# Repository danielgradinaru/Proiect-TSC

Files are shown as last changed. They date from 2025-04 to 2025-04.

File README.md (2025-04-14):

# eBook Reader
Diagram
Proiect hardware complet pentru un eBook Reader portabil, cu consum redus de energie, afisaj E-Paper si conectivitate moderna, proiectat in jurul microcontrollerului ESP32-C6-WROOM-1-N8.

# Arhitectura Hardware

## Microcontroller

### ESP32-C6-WROOM-1-N8
- Core RISC-V
- Conectivitate: Wi-Fi 6, Bluetooth 5
- Criptografie hardware
- [Specificații oficiale](https://www.espressif.com/en/products/modules/esp32-c6)

### Memorie Flash externă
- **W25Q512JVEIQ** – 64MB, conectată prin SPI

### Interfețe disponibile
- I2C, SPI și GPIO dedicate componentelor externe

---

## Alimentare

### USB-C (PMF0501)
- Intrare de 5V din surse standard

### Protecție ESD (USBLC6-2SC6Y)
- Protecție bidirecțională pentru liniile USB

### Încărcător Li-Po (MCP73831)
- Circuit simplu de încărcare pentru o celulă Li-Po (max. 500mA)

### Baterie
- Li-Po 3.7V

### Regulator LDO (MCP1700-3302E)
- Reglează tensiunea la 3.3V pentru alimentarea majorității componentelor

---

## Afișaj E-Ink

### Conector MP1
- Compatibil cu ecrane E-Ink de 1.54", 200x200px

### Circuit de alimentare pentru afișaj
- Componente: Q3 (tranzistor), L1 (inductor), D2 (diodă)
- Rol: generare tensiune specifică pentru EPD

### Selector tip display (SJ1)
- Jumpere pentru alegerea tipului de ecran

### Interfață
- SPI + GPIO, conectat direct la ESP32-C6

---

## Memorie Externă

- **Card SD (U4)** – pentru stocarea fișierelor eBook (conectat prin SPI)
- **64MB NOR Flash (W25Q512JVEIQ)** – memorie extinsă pentru firmware, fonturi, imagini (conectată pe SPI dedicat)

---

## Senzori și Periferice

### BME688
- Senzor pentru temperatură, umiditate, presiune și compuși volatili (VOCs)
- Comunicație: I2C

### RTC – DS3231SN
- Modul de timp real de înaltă precizie
- Comunicație: I2C

### MAX17048G-T10
- Fuel gauge pentru monitorizarea nivelului bateriei
- Comunicație: I2C

### Butoane (BD5229)
- Butoane Reset și Boot
- Conectate pe pini GPIO configurabili

### Qwiic / Stemma QT (J5)
- Conector pentru extensii rapide I2C

---

## Conexiuni ESP32-C6 (pini utilizati)

| Componenta | Interfata  | Pini ESP32-C6 | Observatii |
|---|---|---|---|
| SD Card | SPI | GPIO10, GPIO11, GPIO12, GPIO13 | Bus SPI pentru card SD |
| NOR Flash | SPI | GPIO6, GPIO7, GPIO8, GPIO9 | Bus SPI separat |
| E-Ink Display  | SPI + GPIO | GPIO18, GPIO19, GPIO20, GPIO21 | Control display si date |
| BME688 | I2C | GPIO1 (SDA), GPIO2 (SCL) | Bus comun I2C |
| DS3231 | I2C | GPIO1 (SDA), GPIO2 (SCL) | Comun cu ceilalti senzori |
| MAX17048 | I2C | GPIO1 (SDA), GPIO2 (SCL) | Comun cu ceilalti senzori |
| Butoane | GPIO | GPIO0 (RST), GPIO3 (BOOT) | Control de sistem |
| Test Pads | GPIO/UART  | GPIO17, GPIO22 | Debug |
| Stemma/Qwiic | I2C | GPIO1 (SDA), GPIO2 (SCL) | Extensii rapide |

---

## Estimare consum de energie

| Modul | Consum mediu |
|---|---|
| ESP32-C6 activ | ~80-100 mA |
| ESP32-C6 deep sleep | ~10 uA |
| E-Ink refresh | ~25 mA (temporar) |
| SD Card (idle/acces) | ~2 mA / ~50 mA |
| RTC + BME688 standby | ~3-5 uA |
| MAX17048 | ~3 uA |

**Durata estimata cu baterie 500mAh:**

- Utilizare medie: ~15-20 ore
- Standby (deep sleep): pana la cateva saptamani

---

## Informatii suplimentare

### Structura hardware
- Utilizare medie: ~15-20 ore
- Standby (deep sleep): pana la cateva saptamani

- PCB proiectat cu atentie la separarea blocurilor: alimentare, MCU, afisaj, senzori
- Plan de masa comun, trasee protejate si optimizate
- Mufe si conectori accesibili extern (USB, butoane, afisaj)

### Randari 3D si carcasa

- Randari disponibile cu componentele plasate
- Proiect finalizat atat din punct de vedere al carcasei 3D cat si al PCB
- Dimensiuni compacte si aspect ergonomic

## Aplicatii posibile

- eBook Reader offline
- Afisaj pentru date locale (calendar, vreme)

## Bill of Materials

| Name | Reference | Technical Sheet | Model Link |
|:---|:---|:---|:---|
| BOOT_BUTTON | BUTTON_CUSYOMV1 | [Datasheet](https://industry.panasonic.com/global/en/downloads?tab=catalog&small_g_cd=203&part_no=EVQPUJ02K) | [3D Model](https://industry.panasonic.com/global/en/products/control/switch/light-touch/number/evqpuj02k) |
| C1 | ESP32_WROVER_EAGLE-LTSPICE_CC0402 | [Datasheet](https://componentsearchengine.com/Datasheets/2/CC0402MRX5R5BB106.pdf) | [3D Model](https://componentsearchengine.com/part-view/CC0402MRX5R5BB106/YAGEO) |
| C1_BAT | ESP32_WROVER_EAGLE-LTSPICE_CC0402 | [Datasheet](https://componentsearchengine.com/Datasheets/2/CC0402MRX5R5BB106.pdf) | [3D Model](https://componentsearchengine.com/part-view/CC0402MRX5R5BB106/YAGEO) |
| C1_BAT1 | EAGLE-LTSPICE_CC0402 | [Datasheet](https://s3.amazonaws.com/snapeda/datasheet/CC0402DRNPO9BN5R1_Yageo.pdf) | [3D Model](https://www.snapeda.com/parts/CC0402DRNPO9BN5R1/Yageo/view-part/?ref=dk&t=LTSPICE_CC0402&con_ref=None) |
| C2_BAT1 | EAGLE-LTSPICE_CC0402 | [Datasheet](https://s3.amazonaws.com/snapeda/datasheet/CC0402DRNPO9BN5R1_Yageo.pdf) | [3D Model](https://www.snapeda.com/parts/CC0402DRNPO9BN5R1/Yageo/view-part/?ref=dk&t=LTSPICE_CC0402&con_ref=None) |
| C1_BAT2 | EAGLE-LTSPICE_CC0402 | [Datasheet](https://s3.amazonaws.com/snapeda/datasheet/CC0402DRNPO9BN5R1_Yageo.pdf) | [3D Model](https://www.snapeda.com/parts/CC0402DRNPO9BN5R1/Yageo/view-part/?ref=dk&t=LTSPICE_CC0402&con_ref=None) |
| C2 | ESP32_WROVER_EAGLE-LTSPICE_CC0402 | [Datasheet](https://componentsearchengine.com/Datasheets/2/CC0402MRX5R5BB106.pdf) | [3D Model](https://componentsearchengine.com/part-view/CC0402MRX5R5BB106/YAGEO) |
| C2_BAT | ESP32_WROVER_EAGLE-LTSPICE_CC0402 | [Datasheet](https://componentsearchengine.com/Datasheets/2/CC0402MRX5R5BB106.pdf) | [3D Model](https://componentsearchengine.com/part-view/CC0402MRX5R5BB106/YAGEO) |
| C3 | RCL_CPOL-EUCT3528 | [Datasheet](https://s3.amazonaws.com/snapeda/datasheet/TAJB475K025RNJ_AVX.pdf) | [3D Model](https://www.snapeda.com/parts/TAJB475K025RNJ/AVX/view-part/?ref=dk&t=capacitor%203528&con_ref=None) |
| C4 | ESP32_WROVER_EAGLE-LTSPICE_CC0402 | [Datasheet](https://componentsearchengine.com/Datasheets/2/CC0402MRX5R5BB106.pdf) | [3D Model](https://componentsearchengine.com/part-view/CC0402MRX5R5BB106/YAGEO) |
| C4_USB | ESP32_WROVER_EAGLE-LTSPICE_CC0402 | [Datasheet](https://componentsearchengine.com/Datasheets/2/CC0402MRX5R5BB106.pdf) | [3D Model](https://componentsearchengine.com/part-view/CC0402MRX5R5BB106/YAGEO) |
| C5 | ESP32_WROVER_EAGLE-LTSPICE_CC0402 | [Datasheet](https://componentsearchengine.com/Datasheets/2/CC0402MRX5R5BB106.pdf) | [3D Model](https://componentsearchengine.com/part-view/CC0402MRX5R5BB106/YAGEO) |
| C5_USB | ESP32_WROVER_EAGLE-LTSPICE_CC0402 | [Datasheet](https://componentsearchengine.com/Datasheets/2/CC0402MRX5R5BB106.pdf) | [3D Model](https://componentsearchengine.com/part-view/CC0402MRX5R5BB106/YAGEO) |
| C6 | ESP32_WROVER_EAGLE-LTSPICE_CC0402 | [Datasheet](https://componentsearchengine.com/Datasheets/2/CC0402MRX5R5BB106.pdf) | [3D Model](https://componentsearchengine.com/part-view/CC0402MRX5R5BB106/YAGEO) |
| C7 | ESP32_WROVER_EAGLE-LTSPICE_CC0402 | [Datasheet](https://componentsearchengine.com/Datasheets/2/CC0402MRX5R5BB106.pdf) | [3D Model](https://componentsearchengine.com/part-view/CC0402MRX5R5BB106/YAGEO) |
| C8 | ESP32_WROVER_EAGLE-LTSPICE_CC0402 | [Datasheet](https://componentsearchengine.com/Datasheets/2/CC0402MRX5R5BB106.pdf) | [3D Model](https://componentsearchengine.com/part-view/CC0402MRX5R5BB106/YAGEO) |
| C9 | EAGLE-LTSPICE_CC0402 | [Datasheet](https://s3.amazonaws.com/snapeda/datasheet/CC0402DRNPO9BN5R1_Yageo.pdf) | [3D Model](https://www.snapeda.com/parts/CC0402DRNPO9BN5R1/Yageo/view-part/?ref=dk&t=LTSPICE_CC0402&con_ref=None) |
| C10 | ESP32_WROVER_EAGLE-LTSPICE_CC0402 | [Datasheet](https://componentsearchengine.com/Datasheets/2/CC0402MRX5R5BB106.pdf) | [3D Model](https://componentsearchengine.com/part-view/CC0402MRX5R5BB106/YAGEO) |
| C10_SUPERCAP  | CPH3225A | [Datasheet](https://www.snapeda.com/parts/CPH3225A/Seiko%20Instruments/datasheet/) | [3D Model](https://www.snapeda.com/parts/CPH3225A/Seiko+Instruments/view-part/?ref=eda) |
| CHANGE_BUTTON | BUTTON_CUSYOMV1 | [Datasheet](https://industry.panasonic.com/global/en/downloads?tab=catalog&small_g_cd=203&part_no=EVQPUJ02K) | [3D Model](https://industry.panasonic.com/global/en/products/control/switch/light-touch/number/evqpuj02k) |
| CHG_LED | ADAFRUIT_LEDCHIP-LED0603 | [Datasheet](https://www.snapeda.com/parts/KP-1608SURCK/Kingbright/datasheet/) | [3D Model](https://www.snapeda.com/parts/KP-1608SURCK/Kingbright/view-part/?ref=search&t=LED%200603) |
| C_DELAY | ESP32_WROVER_EAGLE-LTSPICE_CC0402 | [Datasheet](https://componentsearchengine.com/Datasheets/2/CC0402MRX5R5BB106.pdf) | [3D Model](https://componentsearchengine.com/part-view/CC0402MRX5R5BB106/YAGEO) |
| D1 | USBLC6-2SC6Y | [Datasheet](https://www.snapeda.com/parts/USBLC6-2SC6Y/STMicroelectronics/datasheet/) | [3D Model](https://www.snapeda.com/parts/USBLC6-2SC6Y/STMicroelectronics/view-part/?ref=snap) |
| D2 | ESP32_WROVER_AVX---SD0805S020S1R0_AVX_SD0805S020S1R0_0_0AVX_SD0805S020S1R0_0_0 | [Datasheet](http://datasheets.avx.com/schottky.pdf) | [3D Model](https://ro.mouser.com/ProductDetail/KYOCERA-AVX/SD0805S020S1R0?qs=jCA%252BPfw4LHbpkAoSnwrdjw%3D%3D) |
| D3 | MBR0530 | [Datasheet](https://www.snapeda.com/parts/MBR0530/ON%20Semiconductor/datasheet/) | [3D Model](https://www.snapeda.com/parts/MBR0530/Onsemi/view-part/?ref=eda) |
| D4 | MBR0530 | [Datasheet](https://www.snapeda.com/parts/MBR0530/ON%20Semiconductor/datasheet/) | [3D Model](https://www.snapeda.com/parts/MBR0530/Onsemi/view-part/?ref=eda) |
| D5 | MBR0530 | [Datasheet](https://www.snapeda.com/parts/MBR0530/ON%20Semiconductor/datasheet/) | [3D Model](https://www.snapeda.com/parts/MBR0530/Onsemi/view-part/?ref=eda) |
| D6 | PGB1010603MR | [Datasheet](https://www.snapeda.com/parts/PGB1010603MR/Littelfuse%20Inc./datasheet/) | [3D Model](https://www.snapeda.com/parts/PGB1010603MR/Littelfuse/view-part/?ref=eda) |
| D7 | ESP32_WROVER_AVX---SD0805S020S1R0_AVX_SD0805S020S1R0_0_0AVX_SD0805S020S1R0_0_0 | [Datasheet](http://datasheets.avx.com/schottky.pdf) | [3D Model](https://eu.mouser.com/ProductDetail/KYOCERA-AVX/SD0805S020S1R0?qs=jCA%252BPfw4LHbpkAoSnwrdjw%3D%3D) |
| D8 | PGB1010603MR | [Datasheet](https://www.snapeda.com/parts/PGB1010603MR/Littelfuse%20Inc./datasheet/) | [3D Model](https://www.snapeda.com/parts/PGB1010603MR/Littelfuse/view-part/?ref=eda) |
| D9 | PGB1010603MR | [Datasheet](https://www.snapeda.com/parts/PGB1010603MR/Littelfuse%20Inc./datasheet/) | [3D Model](https://www.snapeda.com/parts/PGB1010603MR/Littelfuse/view-part/?ref=eda) |
| D10 | PGB1010603MR | [Datasheet](https://www.snapeda.com/parts/PGB1010603MR/Littelfuse%20Inc./datasheet/) | [3D Model](https://www.snapeda.com/parts/PGB1010603MR/Littelfuse/view-part/?ref=eda) |
| D11 | PGB1010603MR | [Datasheet](https://www.snapeda.com/parts/PGB1010603MR/Littelfuse%20Inc./datasheet/) | [3D Model](https://www.snapeda.com/parts/PGB1010603MR/Littelfuse/view-part/?ref=eda) |
| D12 | PGB1010603MR | [Datasheet](https://www.snapeda.com/parts/PGB1010603MR/Littelfuse%20Inc./datasheet/) | [3D Model](https://www.snapeda.com/parts/PGB1010603MR/Littelfuse/view-part/?ref=eda) |
| EPD_C1 | ESP32_WROVER_EAGLE-LTSPICE_CC0402 | [Datasheet](https://componentsearchengine.com/Datasheets/2/CC0402MRX5R5BB106.pdf) | [3D Model](https://componentsearchengine.com/part-view/CC0402MRX5R5BB106/YAGEO) |
| EPD_C2 | ESP32_WROVER_EAGLE-LTSPICE_CC0402 | [Datasheet](https://componentsearchengine.com/Datasheets/2/CC0402MRX5R5BB106.pdf) | [3D Model](https://componentsearchengine.com/part-view/CC0402MRX5R5BB106/YAGEO) |
| EPD_C5 | ESP32_WROVER_EAGLE-LTSPICE_CC0402 | [Datasheet](https://componentsearchengine.com/Datasheets/2/CC0402MRX5R5BB106.pdf) | [3D Model](https://componentsearchengine.com/part-view/CC0402MRX5R5BB106/YAGEO) |
| EPD_C6 | ESP32_WROVER_EAGLE-LTSPICE_CC0402 | [Datasheet](https://componentsearchengine.com/Datasheets/2/CC0402MRX5R5BB106.pdf) | [3D Model](https://componentsearchengine.com/part-view/CC0402MRX5R5BB106/YAGEO) |
| EPD_C7 | ESP32_WROVER_EAGLE-LTSPICE_CC0402 | [Datasheet](https://componentsearchengine.com/Datasheets/2/CC0402MRX5R5BB106.pdf) | [3D Model](https://componentsearchengine.com/part-view/CC0402MRX5R5BB106/YAGEO) |
| EPD_C8 | ESP32_WROVER_EAGLE-LTSPICE_CC0402 | [Datasheet](https://componentsearchengine.com/Datasheets/2/CC0402MRX5R5BB106.pdf) | [3D Model](https://componentsearchengine.com/part-view/CC0402MRX5R5BB106/YAGEO) |
| EPD_C9 | ESP32_WROVER_EAGLE-LTSPICE_CC0402 | [Datasheet](https://componentsearchengine.com/Datasheets/2/CC0402MRX5R5BB106.pdf) | [3D Model](https://componentsearchengine.com/part-view/CC0402MRX5R5BB106/YAGEO) |
| EPD_C10 | ESP32_WROVER_EAGLE-LTSPICE_CC0402 | [Datasheet](https://componentsearchengine.com/Datasheets/2/CC0402MRX5R5BB106.pdf) | [3D Model](https://componentsearchengine.com/part-view/CC0402MRX5R5BB106/YAGEO) |
| EPD_C11 | ESP32_WROVER_EAGLE-LTSPICE_CC0402 | [Datasheet](https://componentsearchengine.com/Datasheets/2/CC0402MRX5R5BB106.pdf) | [3D Model](https://componentsearchengine.com/part-view/CC0402MRX5R5BB106/YAGEO) |
| EPD_C12 | ESP32_WROVER_EAGLE-LTSPICE_CC0402 | [Datasheet](https://componentsearchengine.com/Datasheets/2/CC0402MRX5R5BB106.pdf) | [3D Model](https://componentsearchengine.com/part-view/CC0402MRX5R5BB106/YAGEO) |
| IC1 | BD5229G-TR | [Datasheet](https://datasheet.datasheetarchive.com/originals/distributors/Datasheets_SAMA/f2b9741ef86007909f138d561a359946.pdf) | [3D Model](https://componentsearchengine.com/part-view/BD5229G-TR/ROHM%20Semiconductor) |
| IC4 | XC6220A331MR-G | [Datasheet](https://product.torexsemi.com/system/files/series/xc6220.pdf) | [3D Model](https://componentsearchengine.com/part-view/XC6220A331MR-G/Torex) |
| J1 | FH34SRJ-24S-0.5SH_99_ | [Datasheet](https://www.hirose.com/en/product/document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) | [3D Model](https://componentsearchengine.com/part-view/FH34SRJ-24S-0.5SH(99)/Hirose) |
| J2 | SAMACSYS_PARTS_USB4110-GF-A | [Datasheet](https://gct.co/files/drawings/usb4110.pdf) | [3D Model](https://componentsearchengine.com/part-view/USB4110-GF-A/GCT%20(GLOBAL%20CONNECTOR%20TECHNOLOGY)) |
| J3 | QWIIC_CONNECTORJS-1MM | [Datasheet](https://eu.mouser.com/ProductDetail/Adafruit/4208?qs=PzGy0jfpSMtbScLbr0L5dw%3D%3D) | [3D Model](https://grabcad.com/library/sparkfun-qwiic-right-angle-1) |
| J4 | 112A-TAAR-R03_ATTEND | [Datasheet](https://store.comet.srl.ro/Catalogue/Product/43497/) | [3D Model](https://store.comet.srl.ro/Catalogue/Product/43497/) |
| L1 | 744043680IND_4828-WE-TPC_WRE | [Datasheet](https://www.we-online.com/components/products/datasheet/744043680.pdf) | [3D Model](https://ro.mouser.com/ProductDetail/Wurth-Elektronik/744043680?qs=PGXP4M47uW6VkZq%252BkzjrHA%3D%3D) |
| PFMF.050.1 | ESP32C6_VARISTORCN1812 | [Datasheet](https://www.mouser.co.uk/ProductDetail/EPCOS-TDK/B72520T0350K062?qs=dEfas%2FXlABIszF52uu7vrg%3D%3D) | [3D Model](https://www.mouser.co.uk/ProductDetail/EPCOS-TDK/B72520T0350K062?qs=dEfas%2FXlABIszF52uu7vrg%3D%3D) |
| Q1 | ESP32_WROVER_SPARKFUN-DISCRETESEMI_MOSFET_PCH-DMG2305UX-7 | [Datasheet](https://www.diodes.com//assets/Datasheets/DMG2305UX.pdf) | [3D Model](https://componentsearchengine.com/part-view/DMG2305UX-7/Diodes%20Incorporated) |
| Q2 | ESP32_WROVER_SPARKFUN-DISCRETESEMI_MOSFET_PCH-DMG2305UX-7 | [Datasheet](https://www.diodes.com//assets/Datasheets/DMG2305UX.pdf) | [3D Model](https://componentsearchengine.com/part-view/DMG2305UX-7/Diodes%20Incorporated) |
| Q3 | D8 | [Datasheet](https://componentsearchengine.com/Datasheets/1/SI1308EDL-T1-GE3.pdf) | [3D Model](https://componentsearchengine.com/part-view/SI1308EDL-T1-GE3/Vishay) |
| R1 | ESP32_WROVER_EAGLE-LTSPICE_RR0402 | [Datasheet](https://www.yageo.com/upload/media/product/products/datasheet/rchip/PYu-RC_Group_51_RoHS_L_12.pdf) | [3D Model](https://componentsearchengine.com/part-view/R0402%201%25%20100%20K%20(RC0402FR-07100KL)/YAGEO) |
| R1-PINH | ESP32_WROVER_EAGLE-LTSPICE_RR0402 | [Datasheet](https://www.yageo.com/upload/media/product/products/datasheet/rchip/PYu-RC_Group_51_RoHS_L_12.pdf) | [3D Model](https://componentsearchengine.com/part-view/R0402%201%25%20100%20K%20(RC0402FR-07100KL)/YAGEO) |
| R1-PINH1 | ESP32_WROVER_EAGLE-LTSPICE_RR0402 | [Datasheet](https://www.yageo.com/upload/media/product/products/datasheet/rchip/PYu-RC_Group_51_RoHS_L_12.pdf) | [3D Model](https://componentsearchengine.com/part-view/R0402%201%25%20100%20K%20(RC0402FR-07100KL)/YAGEO) |
| R1_BAT | ESP32_WROVER_EAGLE-LTSPICE_RR0402 | [Datasheet](https://www.yageo.com/upload/media/product/products/datasheet/rchip/PYu-RC_Group_51_RoHS_L_12.pdf) | [3D Model](https://componentsearchengine.com/part-view/R0402%201%25%20100%20K%20(RC0402FR-07100KL)/YAGEO) |
| R1_PWRUSB | ESP32_WROVER_EAGLE-LTSPICE_RR0402 | [Datasheet](https://www.yageo.com/upload/media/product/products/datasheet/rchip/PYu-RC_Group_51_RoHS_L_12.pdf) | [3D Model](https://componentsearchengine.com/part-view/R0402%201%25%20100%20K%20(RC0402FR-07100KL)/YAGEO) |
| R2 | ESP32_WROVER_EAGLE-LTSPICE_RR0402 | [Datasheet](https://www.yageo.com/upload/media/product/products/datasheet/rchip/PYu-RC_Group_51_RoHS_L_12.pdf) | [3D Model](https://componentsearchengine.com/part-view/R0402%201%25%20100%20K%20(RC0402FR-07100KL)/YAGEO) |
| R2-PINH | ESP32_WROVER_EAGLE-LTSPICE_RR0402 | [Datasheet](https://www.yageo.com/upload/media/product/products/datasheet/rchip/PYu-RC_Group_51_RoHS_L_12.pdf) | [3D Model](https://componentsearchengine.com/part-view/R0402%201%25%20100%20K%20(RC0402FR-07100KL)/YAGEO) |
| R2-PINH1 | ESP32_WROVER_EAGLE-LTSPICE_RR0402 | [Datasheet](https://www.yageo.com/upload/media/product/products/datasheet/rchip/PYu-RC_Group_51_RoHS_L_12.pdf) | [3D Model](https://componentsearchengine.com/part-view/R0402%201%25%20100%20K%20(RC0402FR-07100KL)/YAGEO) |
| R2-USB | ESP32_WROVER_EAGLE-LTSPICE_RR0402 | [Datasheet](https://www.yageo.com/upload/media/product/products/datasheet/rchip/PYu-RC_Group_51_RoHS_L_12.pdf) | [3D Model](https://componentsearchengine.com/part-view/R0402%201%25%20100%20K%20(RC0402FR-07100KL)/YAGEO) |
| R2-USB1 | ESP32_WROVER_EAGLE-LTSPICE_RR0402 | [Datasheet](https://www.yageo.com/upload/media/product/products/datasheet/rchip/PYu-RC_Group_51_RoHS_L_12.pdf) | [3D Model](https://componentsearchengine.com/part-view/R0402%201%25%20100%20K%20(RC0402FR-07100KL)/YAGEO) |
| R2_BAT | ESP32_WROVER_EAGLE-LTSPICE_RR0402 | [Datasheet](https://www.yageo.com/upload/media/product/products/datasheet/rchip/PYu-RC_Group_51_RoHS_L_12.pdf) | [3D Model](https://componentsearchengine.com/part-view/R0402%201%25%20100%20K%20(RC0402FR-07100KL)/YAGEO) |
| R3 | ESP32_WROVER_EAGLE-LTSPICE_RR0402 | [Datasheet](https://www.yageo.com/upload/media/product/products/datasheet/rchip/PYu-RC_Group_51_RoHS_L_12.pdf) | [3D Model](https://componentsearchengine.com/part-view/R0402%201%25%20100%20K%20(RC0402FR-07100KL)/YAGEO) |
| R4 | ESP32_WROVER_EAGLE-LTSPICE_RR0402 | [Datasheet](https://www.yageo.com/upload/media/product/products/datasheet/rchip/PYu-RC_Group_51_RoHS_L_12.pdf) | [3D Model](https://componentsearchengine.com/part-view/R0402%201%25%20100%20K%20(RC0402FR-07100KL)/YAGEO) |
| R5 | ESP32_WROVER_EAGLE-LTSPICE_RR0402 | [Datasheet](https://www.yageo.com/upload/media/product/products/datasheet/rchip/PYu-RC_Group_51_RoHS_L_12.pdf) | [3D Model](https://componentsearchengine.com/part-view/R0402%201%25%20100%20K%20(RC0402FR-07100KL)/YAGEO) |
| R6 | ESP32_WROVER_EAGLE-LTSPICE_RR0402 | [Datasheet](https://www.yageo.com/upload/media/product/products/datasheet/rchip/PYu-RC_Group_51_RoHS_L_12.pdf) | [3D Model](https://componentsearchengine.com/part-view/R0402%201%25%20100%20K%20(RC0402FR-07100KL)/YAGEO) |
| R7 | ESP32_WROVER_EAGLE-LTSPICE_RR0402 | [Datasheet](https://www.yageo.com/upload/media/product/products/datasheet/rchip/PYu-RC_Group_51_RoHS_L_12.pdf) | [3D Model](https://componentsearchengine.com/part-view/R0402%201%25%20100%20K%20(RC0402FR-07100KL)/YAGEO) |
| R8 | ESP32_WROVER_EAGLE-LTSPICE_RR0402 | [Datasheet](https://www.yageo.com/upload/media/product/products/datasheet/rchip/PYu-RC_Group_51_RoHS_L_12.pdf) | [3D Model](https://componentsearchengine.com/part-view/R0402%201%25%20100%20K%20(RC0402FR-07100KL)/YAGEO) |
| R9 | ESP32_WROVER_EAGLE-LTSPICE_RR0402 | [Datasheet](https://www.yageo.com/upload/media/product/products/datasheet/rchip/PYu-RC_Group_51_RoHS_L_12.pdf) | [3D Model](https://componentsearchengine.com/part-view/R0402%201%25%20100%20K%20(RC0402FR-07100KL)/YAGEO) |
| R10 | ESP32_WROVER_EAGLE-LTSPICE_RR0402 | [Datasheet](https://www.yageo.com/upload/media/product/products/datasheet/rchip/PYu-RC_Group_51_RoHS_L_12.pdf) | [3D Model](https://componentsearchengine.com/part-view/R0402%201%25%20100%20K%20(RC0402FR-07100KL)/YAGEO) |
| RESET_BUTTON  | BUTTON_CUSYOMV1 | [Datasheet](https://industry.panasonic.com/global/en/downloads?tab=catalog&small_g_cd=203&part_no=EVQPUJ02K) | [3D Model](https://industry.panasonic.com/global/en/products/control/switch/light-touch/number/evqpuj02k) |
| R_BOOT | ESP32_WROVER_EAGLE-LTSPICE_RR0402 | [Datasheet](https://www.yageo.com/upload/media/product/products/datasheet/rchip/PYu-RC_Group_51_RoHS_L_12.pdf) | [3D Model](https://componentsearchengine.com/part-view/R0402%201%25%20100%20K%20(RC0402FR-07100KL)/YAGEO) |
| R_CAPACITOR | ESP32_WROVER_EAGLE-LTSPICE_RR0402 | [Datasheet](https://www.yageo.com/upload/media/product/products/datasheet/rchip/PYu-RC_Group_51_RoHS_L_12.pdf) | [3D Model](https://componentsearchengine.com/part-view/R0402%201%25%20100%20K%20(RC0402FR-07100KL)/YAGEO) |
| R_CHANGE | ESP32_WROVER_EAGLE-LTSPICE_RR0402 | [Datasheet](https://www.yageo.com/upload/media/product/products/datasheet/rchip/PYu-RC_Group_51_RoHS_L_12.pdf) | [3D Model](https://componentsearchengine.com/part-view/R0402%201%25%20100%20K%20(RC0402FR-07100KL)/YAGEO) |
| R_CL1 | ESP32_WROVER_EAGLE-LTSPICE_RR0402 | [Datasheet](https://www.yageo.com/upload/media/product/products/datasheet/rchip/PYu-RC_Group_51_RoHS_L_12.pdf) | [3D Model](https://componentsearchengine.com/part-view/R0402%201%25%20100%20K%20(RC0402FR-07100KL)/YAGEO) |
| R_RESET | ESP32_WROVER_EAGLE-LTSPICE_RR0402 | [Datasheet](https://www.yageo.com/upload/media/product/products/datasheet/rchip/PYu-RC_Group_51_RoHS_L_12.pdf) | [3D Model](https://componentsearchengine.com/part-view/R0402%201%25%20100%20K%20(RC0402FR-07100KL)/YAGEO) |
| SENSOR2 | ESP32_WROVER_BME680_BME680 | [Datasheet](https://www.snapeda.com/parts/BME680/Bosch%20Sensortec/datasheet/) | [3D Model](https://www.snapeda.com/parts/BME680/Bosch/view-part/?welcome=home) |
| SJ1 | SJ | [Datasheet](https://www.digikey.com/en/htmldatasheets/production/1809569/0/0/1/jumpers) | [3D Model](https://grabcad.com/library/solder-jumpers-1) |
| U1 | W25Q512JVEIQ | [Datasheet](https://www.snapeda.com/parts/W25Q512JVEIQ/Winbond%20Electronics/datasheet/) | [3D Model](https://www.snapeda.com/parts/W25Q512JVEIQ/Winbond+Electronics/view-part/?ref=eda) |
| U2 | ESP32-C6-WROOM-1-N8 | [Datasheet](https://www.snapeda.com/parts/ESP32-C6-WROOM-1-N8/Espressif%20Systems/datasheet/) | [3D Model](https://www.snapeda.com/parts/ESP32-C6-WROOM-1-N8/Espressif+Systems/view-part/?ref=eda) |
| U3 | DS3231SN# | [Datasheet](https://www.snapeda.com/parts/DS3231SN%23/Analog%20Devices/datasheet/) | [3D Model](https://www.snapeda.com/parts/DS3231SN%23/Analog+Devices/view-part/?ref=eda) |
| U4 | MAX17048G+T10 | [Datasheet](https://www.snapeda.com/parts/MAX17048G+T10/Analog%20Devices/datasheet/) | [3D Model](https://www.snapeda.com/parts/MAX17048G+T10/Analog+Devices/view-part/?ref=eda) |
| U5 | ESP32_WROVER_SPARKFUN-IC-POWER_MCP73831 | [Datasheet](https://ro.mouser.com/datasheet/2/268/MCP73831_Family_Data_Sheet_DS20001984H-3441711.pdf) | [3D Model](https://ro.mouser.com/ProductDetail/Microchip-Technology/MCP73831T-2ACI-OT?qs=yUQqVecv4qvbBQBGbHx0Mw%3D%3D) |
| TP1 | TPTP20R | | |
| TP2 | TPTP20R | | |
| TP3 | TPTP20R | | |
| TP4 | TPTP20R | | |
| TP5 | TPTP20R | | |
| TP6 | TPTP20R | | |
| TP7 | TPTP20R | | |
| TP8 | TPTP20R | | |
| TP9 | TPTP20R | | |
| TP10 | TPTP20R | | |
| TP11 | TPTP20R | | |
| TP12 | TPTP20R | | |
| TP13 | TPTP20R | | |
| TP14 | TPTP20R | | |
| TP15 | TPTP20R | | |
| TP16 | TPTP20R | | |

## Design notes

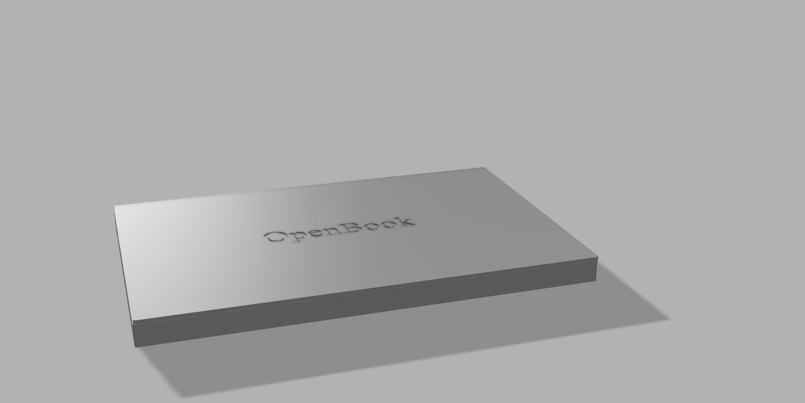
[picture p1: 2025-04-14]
Images/Back.png

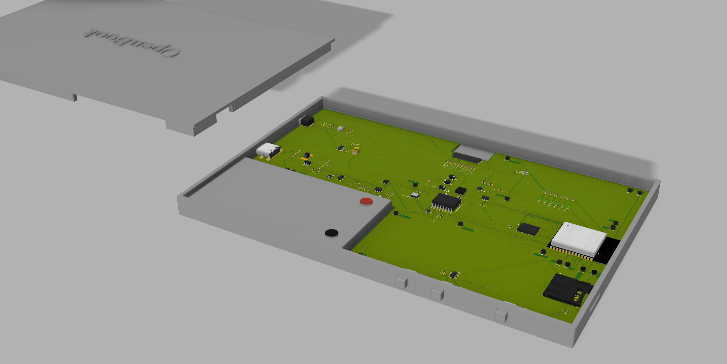
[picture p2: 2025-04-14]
Images/PCB2.png

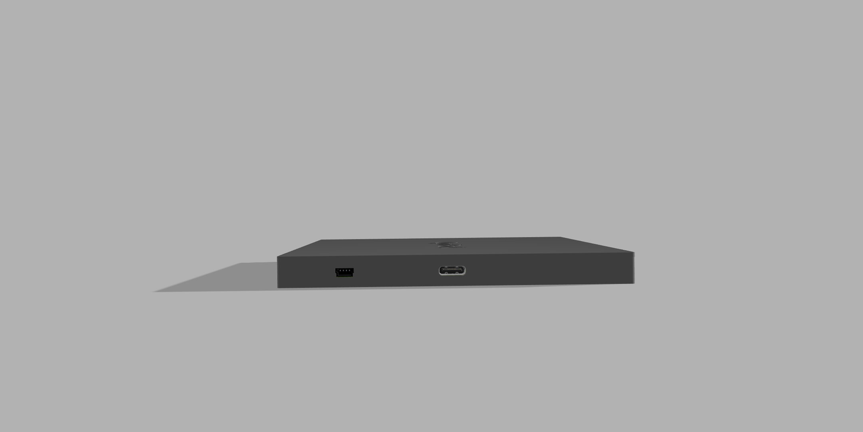
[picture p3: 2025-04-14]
Images/Side.png

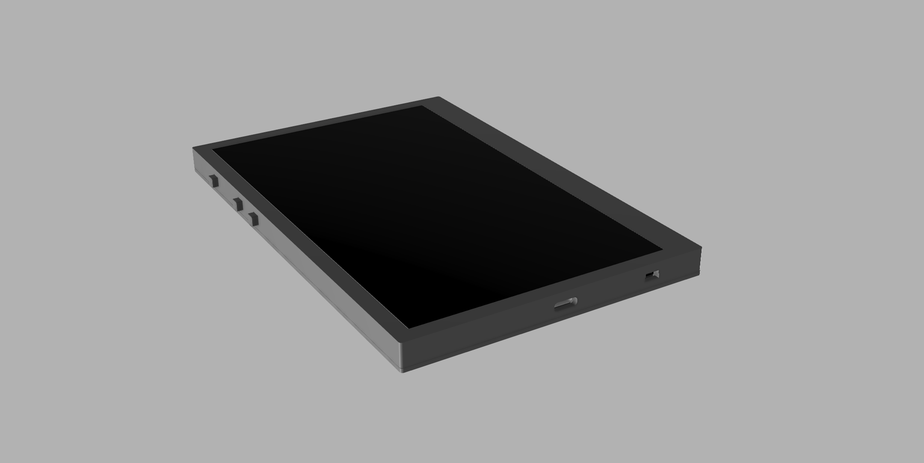
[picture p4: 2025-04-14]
Images/Front.png

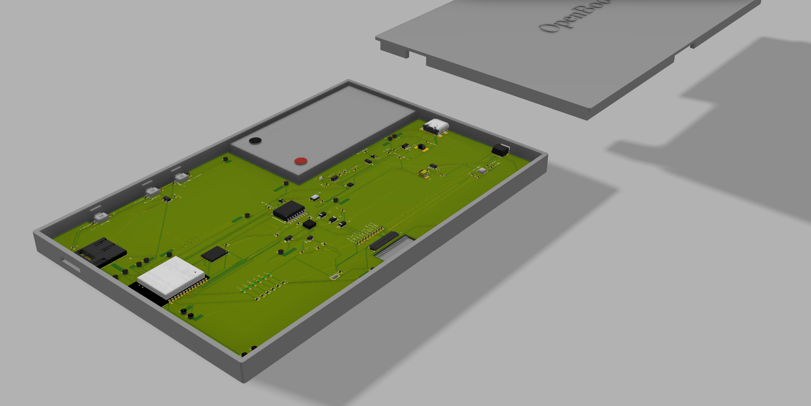
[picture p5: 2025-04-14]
Images/PCB.png

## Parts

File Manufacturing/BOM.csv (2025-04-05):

Qty | Value | Device | Package | Parts | Description | ARROW_PART_NUMBER | ARROW_PRICE-STOCK | AVAILABILITY | CENTROID_NOT_SPECIFIED | CHECK_PRICES | COPYRIGHT | DATASHEET | DESCRIPTION | DIGIKEY_DESCRIPTION | DIGIKEY_PART_NUMBER | HEIGHT | LEAD_FREE | MANUFACTURER_NAME | MANUFACTURER_PART_NUMBER | MF | MFR_NAME | MOUSER_PART_NUMBER | MOUSER_PRICE-STOCK | MOUSER_TESTING_PART_NUMBER | MOUSER_TESTING_PRICE-STOCK | MP | MPN | PACKAGE | POPULARITY | PREFIX | PRICE | PROD_ID | PURCHASE-URL | ROHS | SNAPEDA_LINK | SPICEMODEL | SPICEPREFIX | TEMPERATURE_RANGE_HIGH | TEMPERATURE_RANGE_LOW | TP_SIGNAL_NAME | VALUE
1 |  | ADAFRUIT_LEDCHIP-LED0603 | ADAFRUIT_CHIP-LED0603 | CHG_LED | LED
1 |  | SJ | SJ | SJ1 | SMD solder JUMPER |  |  |  |  |  |  |  |  |  |  |  |  |  |  |  |  |  |  |  |  |  |  |  | 3
1 | 0.47 | ESP32_WROVER_EAGLE-LTSPICE_RR0402 | ESP32_WROVER_EAGLE-LTSPICE_R0402 | R3 | RESISTOR, European symbol |  |  |  |  |  |  |  |  |  |  |  |  |  |  |  |  |  |  |  |  |  |  |  |  |  |  |  |  |  |  | NONE | R
1 | 100K | ESP32_WROVER_EAGLE-LTSPICE_RR0402 | ESP32_WROVER_EAGLE-LTSPICE_R0402 | R1_PWRUSB | RESISTOR, European symbol |  |  |  |  |  |  |  |  |  |  |  |  |  |  |  |  |  |  |  |  |  |  |  |  |  |  |  |  |  |  | NONE | R
8 | 100nF | EAGLE-LTSPICE_CC0402 | EAGLE-LTSPICE_C0402 | C1, C2, C4_USB, C6, C8, C9, C10, C_DELAY | CAPACITOR, European symbol |  |  |  |  |  |  |  |  |  |  |  |  |  |  |  |  |  |  |  |  |  |  |  |  |  |  |  |  |  |  | NONE | C
1 | 100uF | RCL_CPOL-EUCT3528 | RCL_CT3528 | C3 | POLARIZED CAPACITOR, European symbol |  |  |  |  |  |  |  |  |  |  |  |  |  |  |  |  |  |  |  |  |  |  |  | 0 |  |  |  |  |  |  |  | C
16 | 10K | ESP32_WROVER_EAGLE-LTSPICE_RR0402 | ESP32_WROVER_EAGLE-LTSPICE_R0402 | R1, R1-PINH, R1_PINH1, R2-PINH, R2_PINH1, R4, R5, R6, R7, R8, R9, R10, R_BOOT, R_CHANGE, R_CL1, R_RESET | RESISTOR, European symbol |  |  |  |  |  |  |  |  |  |  |  |  |  |  |  |  |  |  |  |  |  |  |  |  |  |  |  |  |  |  | NONE | R
1 | 10uF | EAGLE-LTSPICE_CC0402 | EAGLE-LTSPICE_C0402 | C7 | CAPACITOR, European symbol |  |  |  |  |  |  |  |  |  |  |  |  |  |  |  |  |  |  |  |  |  |  |  |  |  |  |  |  |  |  | NONE | C
1 | 112A-TAAR-R03_ATTEND | 112A-TAAR-R03_ATTEND | 112ATAARR03ATTEND | J4 | Micro SD Card Socket, Push-Push Type, Top Mount, SMT, H=1.83mm, 10u |  |  |  |  |  |  |  | Micro SD Card Socket | Push-Push Type | Top Mount | SMT | H=1.83mm | 10u |  |  | 1.9mm |  | ATTEND | 112A-TAAR-R03 ATTEND
1 | 15 | ESP32_WROVER_EAGLE-LTSPICE_RR0402 | ESP32_WROVER_EAGLE-LTSPICE_R0402 | R_CAPACITOR | RESISTOR, European symbol |  |  |  |  |  |  |  |  |  |  |  |  |  |  |  |  |  |  |  |  |  |  |  |  |  |  |  |  |  |  | NONE | R
1 | 1uF | EAGLE-LTSPICE_CC0402 | EAGLE-LTSPICE_C0402 | C5 | CAPACITOR, European symbol |  |  |  |  |  |  |  |  |  |  |  |  |  |  |  |  |  |  |  |  |  |  |  |  |  |  |  |  |  |  | NONE | C
10 | 1uF/50V | EAGLE-LTSPICE_CC0402 | EAGLE-LTSPICE_C0402 | EPD_C1, EPD_C2, EPD_C5, EPD_C6, EPD_C7, EPD_C8, EPD_C9, EPD_C10, EPD_C11, EPD_C12 | CAPACITOR, European symbol |  |  |  |  |  |  |  |  |  |  |  |  |  |  |  |  |  |  |  |  |  |  |  |  |  |  |  |  |  |  | NONE | C
1 | 2.2 | ESP32_WROVER_EAGLE-LTSPICE_RR0402 | ESP32_WROVER_EAGLE-LTSPICE_R0402 | R2 | RESISTOR, European symbol |  |  |  |  |  |  |  |  |  |  |  |  |  |  |  |  |  |  |  |  |  |  |  |  |  |  |  |  |  |  | NONE | R
1 | 200 | ESP32_WROVER_EAGLE-LTSPICE_RR0402 | ESP32_WROVER_EAGLE-LTSPICE_R0402 | R1_BAT | RESISTOR, European symbol |  |  |  |  |  |  |  |  |  |  |  |  |  |  |  |  |  |  |  |  |  |  |  |  |  |  |  |  |  |  | NONE | R
2 | 20V/4.2A/52m?/1.4W | ESP32_WROVER_SPARKFUN-DISCRETESEMI_MOSFET_PCH-DMG2305UX-7 | ESP32_WROVER_SPARKFUN-DISCRETESEMI_SOT23-3 | Q1, Q2 | P-channel MOSFETs |  |  |  |  |  |  |  |  |  |  |  |  |  |  |  |  |  |  |  |  |  |  |  |  |  |  | TRAN-14388 |  |  |  |  |  |  |  |  | 20V/4.2A/52m?/1.4W
1 | 2K | ESP32_WROVER_EAGLE-LTSPICE_RR0402 | ESP32_WROVER_EAGLE-LTSPICE_R0402 | R2_BAT | RESISTOR, European symbol |  |  |  |  |  |  |  |  |  |  |  |  |  |  |  |  |  |  |  |  |  |  |  |  |  |  |  |  |  |  | NONE | R
4 | 4.7uF | EAGLE-LTSPICE_CC0402 | EAGLE-LTSPICE_C0402 | C1_BAT, C1_BAT2, C2_BAT, C5_USB | CAPACITOR, European symbol |  |  |  |  |  |  |  |  |  |  |  |  |  |  |  |  |  |  |  |  |  |  |  |  |  |  |  |  |  |  | NONE | C
1 | 4.7uF | ESP32_WROVER_EAGLE-LTSPICE_CC0402 | ESP32_WROVER_EAGLE-LTSPICE_C0402 | C1_BAT1 | CAPACITOR, European symbol |  |  |  |  |  |  |  |  |  |  |  |  |  |  |  |  |  |  |  |  |  |  |  |  |  |  |  |  |  |  | NONE | C
1 | 4.7uF/25V | EAGLE-LTSPICE_CC0402 | EAGLE-LTSPICE_C0402 | C4 | CAPACITOR, European symbol |  |  |  |  |  |  |  |  |  |  |  |  |  |  |  |  |  |  |  |  |  |  |  |  |  |  |  |  |  |  | NONE | C
1 | 5K1 | ESP32_WROVER_EAGLE-LTSPICE_RR0402 | ESP32_WROVER_EAGLE-LTSPICE_R0402 | R2-USB1 | RESISTOR, European symbol |  |  |  |  |  |  |  |  |  |  |  |  |  |  |  |  |  |  |  |  |  |  |  |  |  |  |  |  |  |  | NONE | R
1 | 5k1 | ESP32_WROVER_EAGLE-LTSPICE_RR0402 | ESP32_WROVER_EAGLE-LTSPICE_R0402 | R2-USB | RESISTOR, European symbol |  |  |  |  |  |  |  |  |  |  |  |  |  |  |  |  |  |  |  |  |  |  |  |  |  |  |  |  |  |  | NONE | R
1 | 68uH | 744043680IND_4828-WE-TPC_WRE | IND_4828-WE-TPC_WRE | L1 |  |  |  |  |  |  | Copyright (C) 2024 Ultra Librarian. All rights reserved. |  |  |  |  |  |  |  | 744043680 |  | Wurth Electronics
1 | BD5229G-TR | BD5229G-TR | SOT95P280X125-5N | IC1 | Voltage Detector with Adjustable Delay Time: CMOS processes are utilized to develop high precision, low current consumption CMOS reset ICs that allow arbitrary setting of the delay time. The extensive lineup includes both Nch Open Drain and CMOS output types in a wide range of detection voltages (from 2.3V to 6.0V, in 0.1V steps), enabling selection of the ideal solution based on customer requirements. In addition, the entire series is of course both lead-free and RoHS-compliant. |  |  |  |  |  |  |  | Voltage Detector with Adjustable Delay Time: CMOS processes are utilized to develop high precision | low current consumption CMOS reset ICs that allow arbitrary setting of the delay time. The extensive lineup includes both Nch Open Drain and CMOS output types in a wide range of detection voltages (from 2.3V to 6.0V | in 0.1V steps) | enabling selection of the ideal solution based on customer requirements. In addition | the entire series is of course both lead-free and RoHS-compliant. |  |  | 1.25mm |  | ROHM Semiconductor | BD5229G-TR |  |  | 755-BD5229G-TR | https://www.mouser.co.uk/ProductDetail/ROHM-Semiconductor/BD5229G-TR?qs=4kLU8WoGk0vvnhrrYwdszw%3D%3D
1 | BME688 | ESP32_WROVER_BME680_BME680 | ESP32_WROVER_BME680_PSON80P300X300X100-8N | SENSOR2 | Integrated Environmental Unit |  |  | Unavailable |  |  |  |  | Integrated Environmental Unit |  |  |  |  |  |  | Bosch Sensortec |  |  |  |  |  | BME680 |  | LGA-8 Bosch Tools |  |  | None
3 | BUTTON_CUSYOMV1 | BUTTON_CUSYOMV1 | MYBUTTON | BOOT_BUTTON, CHANGE_BUTTON, RESET_BUTTON
1 | CPH3225A | CPH3225A | CAPCP3225X100N | C10_SUPERCAP | Cap 0.011F 3.3V 1210 Flat Check availability |  |  | Not in stock |  | https://www.snapeda.com/parts/CPH3225A/Seiko+Instruments/view-part/?ref=eda |  |  | 11 mF (EDLC) Supercapacitor 3.3 V 1210 (3225 Metric) - - |  |  |  |  |  |  | Seiko Instruments |  |  |  |  |  | CPH3225A |  | 1210 Seiko |  |  | None |  | https://www.snapeda.com/api/url_track_click_mouser/?unipart_id=562593&manufacturer=Seiko Instruments&part_name=CPH3225A&search_term=None |  | https://www.snapeda.com/parts/CPH3225A/Seiko+Instruments/view-part/?ref=snap
1 | DS3231SN# | DS3231SN# | SOIC127P1032X265-16N | U3 | Real Time Clock Serial 16-Pin SOIC W T/R Check availability |  |  | In Stock |  | https://www.snapeda.com/parts/DS3231SN%23/Analog+Devices/view-part/?ref=eda |  |  | Extremely Accurate I2C-Integrated RTC/TCXO/Crystal |  |  |  |  |  |  | Analog Devices |  |  |  |  |  | DS3231SN# |  | SOIC-16 Maxim |  |  | None |  | https://www.snapeda.com/api/url_track_click_mouser/?unipart_id=99048&manufacturer=Analog Devices&part_name=DS3231SN#&search_term=None |  | https://www.snapeda.com/parts/DS3231SN%23/Analog+Devices/view-part/?ref=snap
1 | ESP32-C6-WROOM-1-N8 | ESP32-C6-WROOM-1-N8 | XCVR_ESP32-C6-WROOM-1-N8 | U1 | Check availability |  |  | In Stock |  | https://www.snapeda.com/parts/ESP32-C6-WROOM-1-N8/Espressif+Systems/view-part/?ref=eda |  |  | Multiprotocol Modules ESP32-C6 module | Wi-Fi 6 in 2.4 GHz band | Bluetooth 5 | Zigbee 3.0 and Thread. ESP34-WROOM Compatible - ENGINEERING SAMPLE |  |  |  |  |  |  | Espressif Systems |  |  |  |  |  | ESP32-C6-WROOM-1-N8 |  | None |  |  | None |  |  |  | https://www.snapeda.com/parts/ESP32-C6-WROOM-1-N8/Espressif+Systems/view-part/?ref=snap
1 | ESP32C6_VARISTORCN1812 | ESP32C6_VARISTORCN1812 | ESP32C6_VARISTOR_CT/CN1812 | PFMF.050.1 | VARISTOR |  |  |  |  |  |  |  |  |  |  |  |  |  |  |  |  |  |  |  |  |  |  |  | 0
2 | ESP32_WROVER_AVX---SD0805S020S1R0_AVX_SD0805S020S1R0_0_0AVX_SD0805S020S1R0_0_0 | ESP32_WROVER_AVX---SD0805S020S1R0_AVX_SD0805S020S1R0_0_0AVX_SD0805S020S1R0_0_0 | ESP32_WROVER_AVX---SD0805S020S1R0_AVX_SD0805S020S1R0_0 | D2, D7 | Schottky Barrier Rectifier Diode |  |  |  | No |  |  | http://datasheets.avx.com/schottky.pdf |  | DIODE SCHOTTKY 20V 1A 0805 | 478-7800-1-ND |  | yes |  |  | AVX |  | 581-SD0805S020S1R0 |  |  |  |  |  | 0805 (2012 metric) |  | D |  |  |  | yes |  |  |  | +125°C | -55°C
1 | ESP32_WROVER_SPARKFUN-IC-POWER_MCP73831 | ESP32_WROVER_SPARKFUN-IC-POWER_MCP73831 | ESP32_WROVER_SPARKFUN-IC-POWER_SOT23-5 | MCP73831 | MCP73831T Li-Ion, Li-Pol Controller |  |  |  |  |  |  |  |  |  |  |  |  |  |  |  |  |  |  |  |  |  |  |  |  |  |  | IC-09995
1 | FH34SRJ-24S-0.5SH_99_ | FH34SRJ-24S-0.5SH_99_ | FH34SRJ24S05SH99 | J1 | (0.50mm) Surface Mount, Right Angle |  |  |  |  |  |  |  | 24 Position FFC | FPC Connector Contacts | (0.50mm) Surface Mount | Right Angle |  |  | 1.1mm |  | Hirose | FH34SRJ-24S-0.5SH(99) |  |  | 798-FH34SRJ24S05SH99 | https://www.mouser.co.uk/ProductDetail/Hirose-Connector/FH34SRJ-24S-0.5SH99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
1 | MAX17048G+T10 | MAX17048G+T10 | SON50P200X200X80-9N | U4 | Check availability |  |  | In Stock |  | https://www.snapeda.com/parts/MAX17048G+T10/Analog+Devices/view-part/?ref=eda |  |  | 3µA 1-Cell/2-Cell Fuel Gauge with ModelGauge |  |  |  |  |  |  | Analog Devices |  |  |  |  |  | MAX17048G+T10 |  | TDFN-8 Maxim |  |  | None |  | https://www.snapeda.com/api/url_track_click_mouser/?unipart_id=329239&manufacturer=Analog Devices&part_name=MAX17048G+T10&search_term=None |  | https://www.snapeda.com/parts/MAX17048G+T10/Analog+Devices/view-part/?ref=snap
3 | MBR0530 | MBR0530 | SOD3716X135N | D3, D4, D5 | ON SEMICONDUCTOR - MBR0530 - DIODE, SCHOTTKY, 0.5A, 30V, SOD-123 |  |  | In Stock |  | https://www.snapeda.com/parts/MBR0530/Onsemi/view-part/?ref=eda |  |  | Diode Schottky 30 V 500mA Surface Mount SOD-123 |  |  |  |  |  |  | ON Semiconductor |  |  |  |  |  | MBR0530 |  | SOD-123-2 ON Semiconductor |  |  | None |  | https://www.snapeda.com/api/url_track_click_mouser/?unipart_id=179458&manufacturer=ON Semiconductor&part_name=MBR0530&search_term=None |  | https://www.snapeda.com/parts/MBR0530/Onsemi/view-part/?ref=snap
6 | PGB1010603MR | PGB1010603MR | DIOC1608X36N | D6, D8, D9, D10, D11, D12 | Check availability |  |  | In Stock |  | https://www.snapeda.com/parts/PGB1010603MR/Littelfuse/view-part/?ref=eda |  |  | 150V (Typ) Clamp - Ipp Tvs Diode Surface Mount 0603 (1608 Metric) |  |  |  |  |  |  | Littelfuse Inc. |  |  |  |  |  | PGB1010603MR |  | 0603 Littelfuse Inc. |  |  | None |  | https://www.snapeda.com/api/url_track_click_mouser/?unipart_id=5659453&manufacturer=Littelfuse Inc.&part_name=PGB1010603MR&search_term=None |  | https://www.snapeda.com/parts/PGB1010603MR/Littelfuse/view-part/?ref=snap
1 | QWIIC_RIGHT_ANGLE | QWIIC_CONNECTORJS-1MM | JST04_1MM_RA | J3 | SparkFun I2C Standard Qwiic Connector |  |  |  |  |  |  |  |  |  |  |  |  |  |  |  |  |  |  |  |  |  |  |  |  |  |  | CONN-13694 |  |  |  |  |  |  |  |  | QWIIC_RIGHT_ANGLE
1 | SAMACSYS_PARTS_USB4110-GF-A | SAMACSYS_PARTS_USB4110-GF-A | SAMACSYS_PARTS_USB4110GFA | J2 | CONN USB 2.0 TYPE-C R/A SMT |  |  |  |  |  |  |  | CONN USB 2.0 TYPE-C R/A SMT |  |  | 3.26mm |  | GCT (GLOBAL CONNECTOR TECHNOLOGY) | USB4110-GF-A |  |  | 640-USB4110-GF-A | https://www.mouser.co.uk/ProductDetail/GCT/USB4110-GF-A?qs=KUoIvG%2F9IlYiZvIXQjyJeA%3D%3D
1 | SI1308EDL-T1-GE3 | SI1308EDL-T1-GE3 | SOT65P210X110-3N | Q3 | MOSFET N-Ch 30V 1.5A TrenchFET SC70 Vishay Si1308EDL-T1-GE3 N-channel MOSFET Transistor, 1.5 A, 30 V, 3-Pin SC-70 |  |  | In Stock |  | https://www.snapeda.com/parts/SI1308EDL-T1-GE3/Vishay+Siliconix/view-part/?ref=eda |  |  | Si1308EDL-T1-GE3 N-channel MOSFET Transistor | 1.5 A | 30 V | 3-Pin SC-70 | Siliconix / Vishay SI1308EDL-T1-GE3 |  |  |  |  |  |  | Vishay Siliconix |  |  |  |  |  | SI1308EDL-T1-GE3 |  | SOT-323 Vishay Semiconductor |  |  | None |  | https://www.snapeda.com/api/url_track_click_mouser/?unipart_id=274603&manufacturer=Vishay Siliconix&part_name=SI1308EDL-T1-GE3&search_term=None |  | https://www.snapeda.com/parts/SI1308EDL-T1-GE3/Vishay+Siliconix/view-part/?ref=snap
17 | TPTP20R | TPTP20R | TP20R | TP1, TP2, TP3, TP4, TP5, TP6, TP7, TP8, TP9, TP10, TP11, TP12, TP13, TP14, TP15, TP16, TP17 | Test pad |  |  |  |  |  |  |  |  |  |  |  |  |  |  |  |  |  |  |  |  |  |  |  | 2
1 | USBLC6-2SC6Y | USBLC6-2SC6Y | SOT95P280X145-6N | D1 | Low Cap. ESD Protection Auto SOT-23-6 STMicroelectronics USBLC6-2SC6Y, Dual Uni-Directional TVS Diode Array, 6-Pin SOT-23 |  |  | In Stock |  | https://www.snapeda.com/parts/USBLC6-2SC6Y/STMicroelectronics/view-part/?ref=eda |  |  | 17V Clamp 5A (8/20µs) Ipp Tvs Diode Surface Mount SOT-23-6 |  |  |  |  |  |  | STMicroelectronics |  |  |  |  |  | USBLC6-2SC6Y |  | SOT-23-6 STMicroelectronics |  |  | None |  |  |  | https://www.snapeda.com/parts/USBLC6-2SC6Y/STMicroelectronics/view-part/?ref=snap
1 | W25Q512JVEIQ | W25Q512JVEIQ | SON127P600X800X80-9N | U2 | Check availability |  |  | In Stock |  | https://www.snapeda.com/parts/W25Q512JVEIQ/Winbond+Electronics/view-part/?ref=eda |  |  | FLASH - NOR Memory IC 512Mb (64M x 8) SPI - Quad I/O 133 MHz 8-WSON (8x6) |  |  |  |  |  |  | Winbond Electronics |  |  |  |  |  | W25Q512JVEIQ |  | Package |  |  | None |  |  |  | https://www.snapeda.com/parts/W25Q512JVEIQ/Winbond+Electronics/view-part/?ref=snap
1 | XC6220A331MR-G | XC6220A331MR-G | SOT95P280X120-5N | IC4 | LDO Voltage Regulators |  |  |  |  |  |  |  | LDO Voltage Regulators |  |  | 1.2mm |  | Torex | XC6220A331MR-G |  |  | 865-XC6220A331MR-G | https://www.mouser.co.uk/ProductDetail/Torex-Semiconductor/XC6220A331MR-G?qs=AsjdqWjXhJ8ZSWznL1J0gg%3D%3D

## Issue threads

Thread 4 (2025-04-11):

[SCH] Texte ilizibile

AlinS1, 2025-04-11:
Textele urmatoare se suprapun si sunt greu de citit. Pot fi micsorate si aliniate pentru a fi mai lizibile:
- EPD_C6-12 din zona E-Paper Display Header .
- BUTTON_CUSYOMV1 in sectiunea Voltage Supervisor + Reset & Boot / IO Button

Closed 2025-04-14.

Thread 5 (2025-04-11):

[SCH] Warnings neaprobate sau nesolutionate

AlinS1, 2025-04-11:
La nivelul schemei am vazut ca au ramas warnings care ar trebui aprobate sau rezolvate.
Printre ele, warning-urile "Net PREVGH overlaps pin" si "Close but unconnected wires in nets PREVGH and GND" pot fi rezolvat prin mutarea lui EPD_C10 mai la dreapta.

Closed 2025-04-14.

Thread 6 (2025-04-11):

[BRD] Board Outline Clearance Error - J2

AlinS1, 2025-04-11:
La nivelul board-ului am vazut ca a ramas o eroare care trebuie aprobata sau rezolvata:
- Board Outline Clearance la J2 (SMD-Hole).

Closed 2025-04-14.

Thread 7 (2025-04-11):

[BRD] Gauri in planul de masa (TOP & BOTTOM)

AlinS1, 2025-04-11:
Planul de masa nu acopera intreaga placa. Una dintre gaurile de pe TOP poate fi umpluta prin plasarea unui via pe o portiune cu plan de masa pe BOTTOM, urmat de Polygon Pour.

Closed 2025-04-14.

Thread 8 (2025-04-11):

[BRD] Prezenta unor unghiuri drepte pe trasee.

AlinS1, 2025-04-11:
Sunt de evitat unghiurile de 90° in trasee.
Exemple coordonate:
- 94, -21 pe traseul 3V3 pe TOP
- 107.1, 5.5 pe traseul EPD_DC pe BOTTOM
- 110.4, -2.3 pe traseul EPD_CS pe BOTTOM
- 82.1, -9.9 pe traseul EPD_CS pe BOTTOM
- 78.6, -8.6 pe traseul PREVGH pe BOTTOM
- 165.5, 21.4 pe traseul N$1 pe BOTTOM
- 10.5, 77.1 pe traseul RESET pe BOTTOM
- 6.5, 33.4 pe traseul MISO pe BOTTOM

Closed 2025-04-14.

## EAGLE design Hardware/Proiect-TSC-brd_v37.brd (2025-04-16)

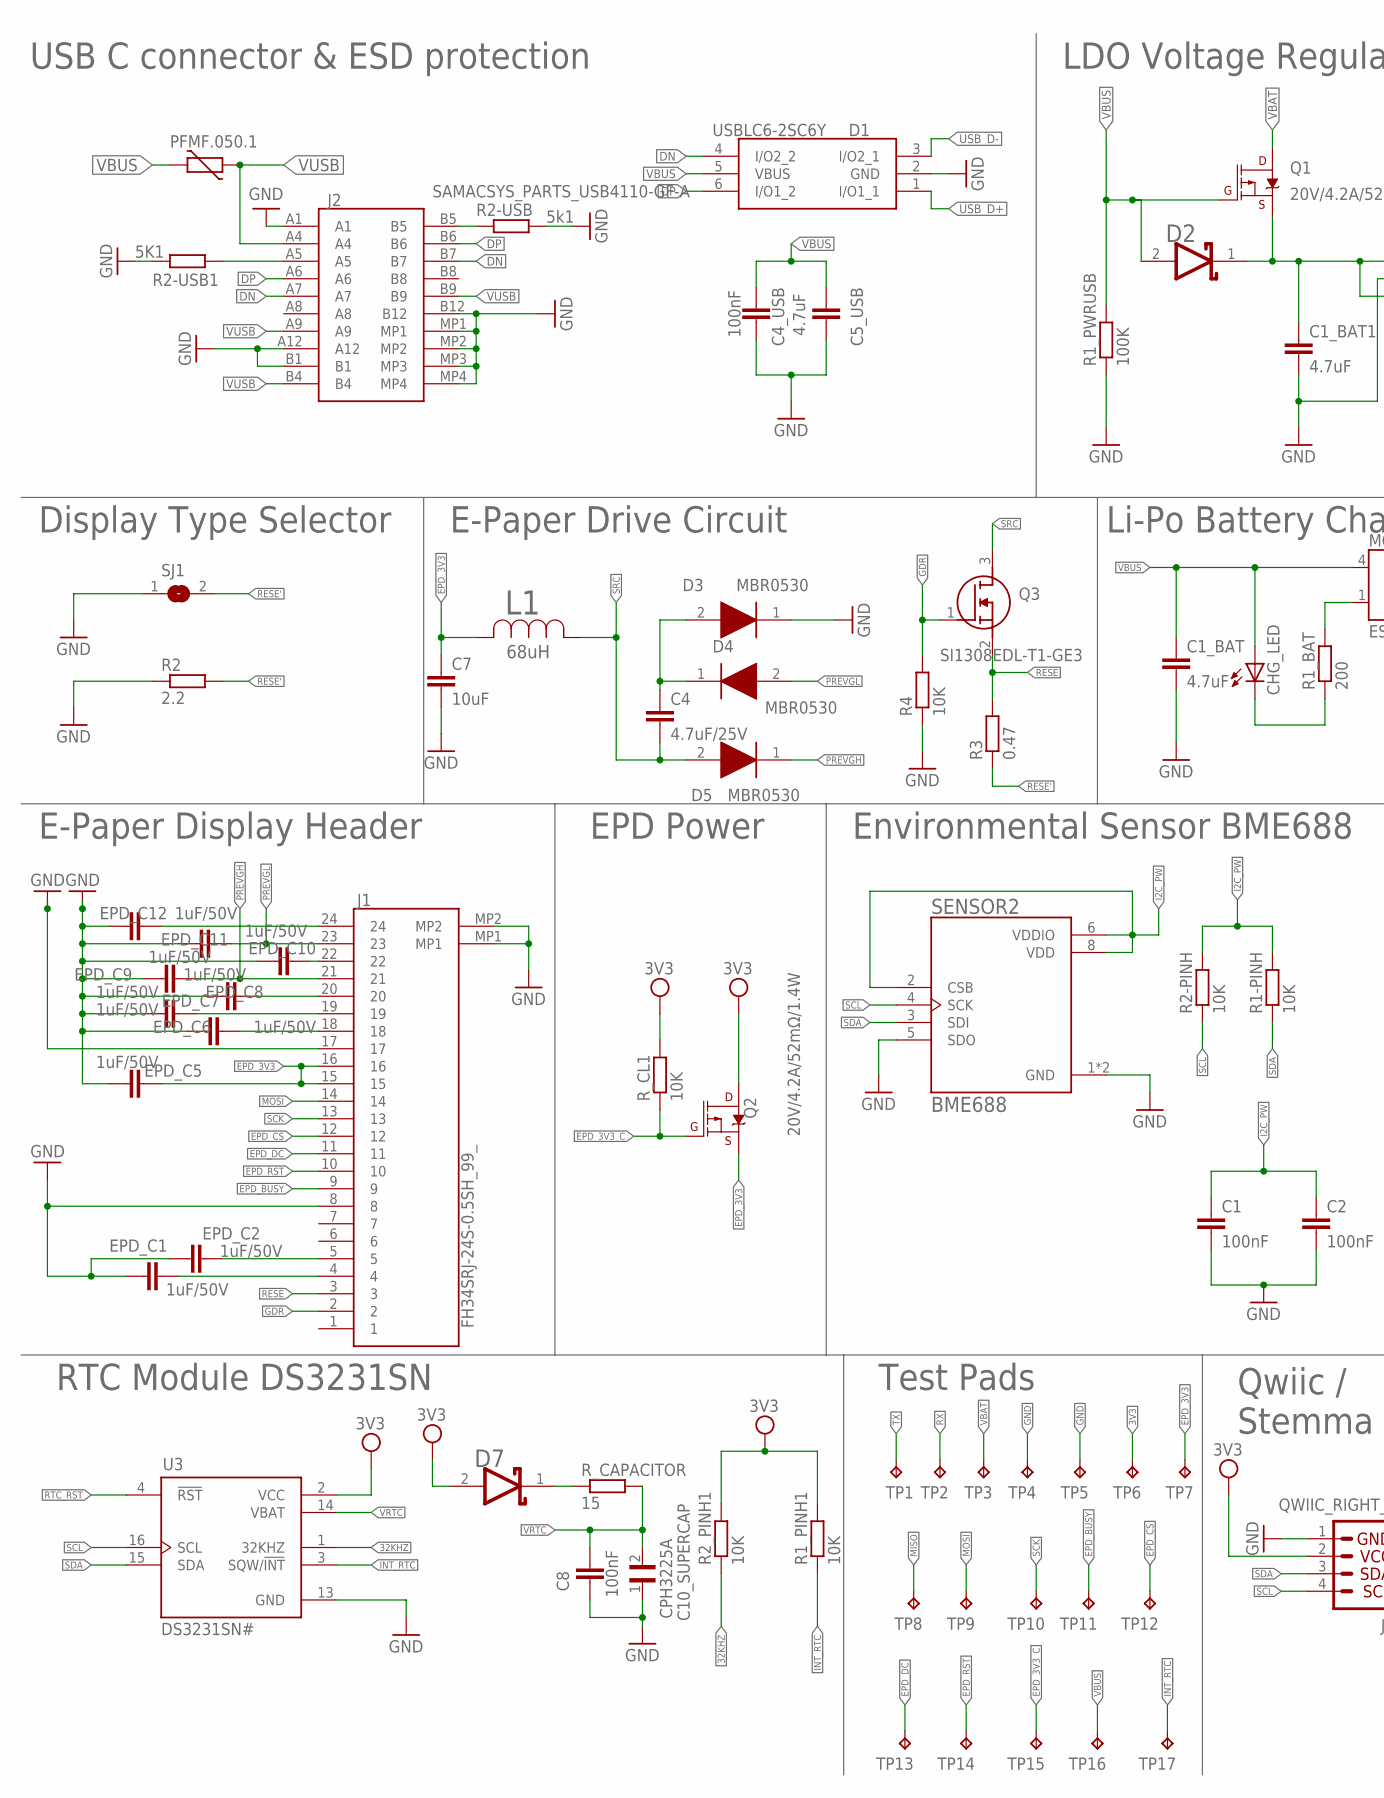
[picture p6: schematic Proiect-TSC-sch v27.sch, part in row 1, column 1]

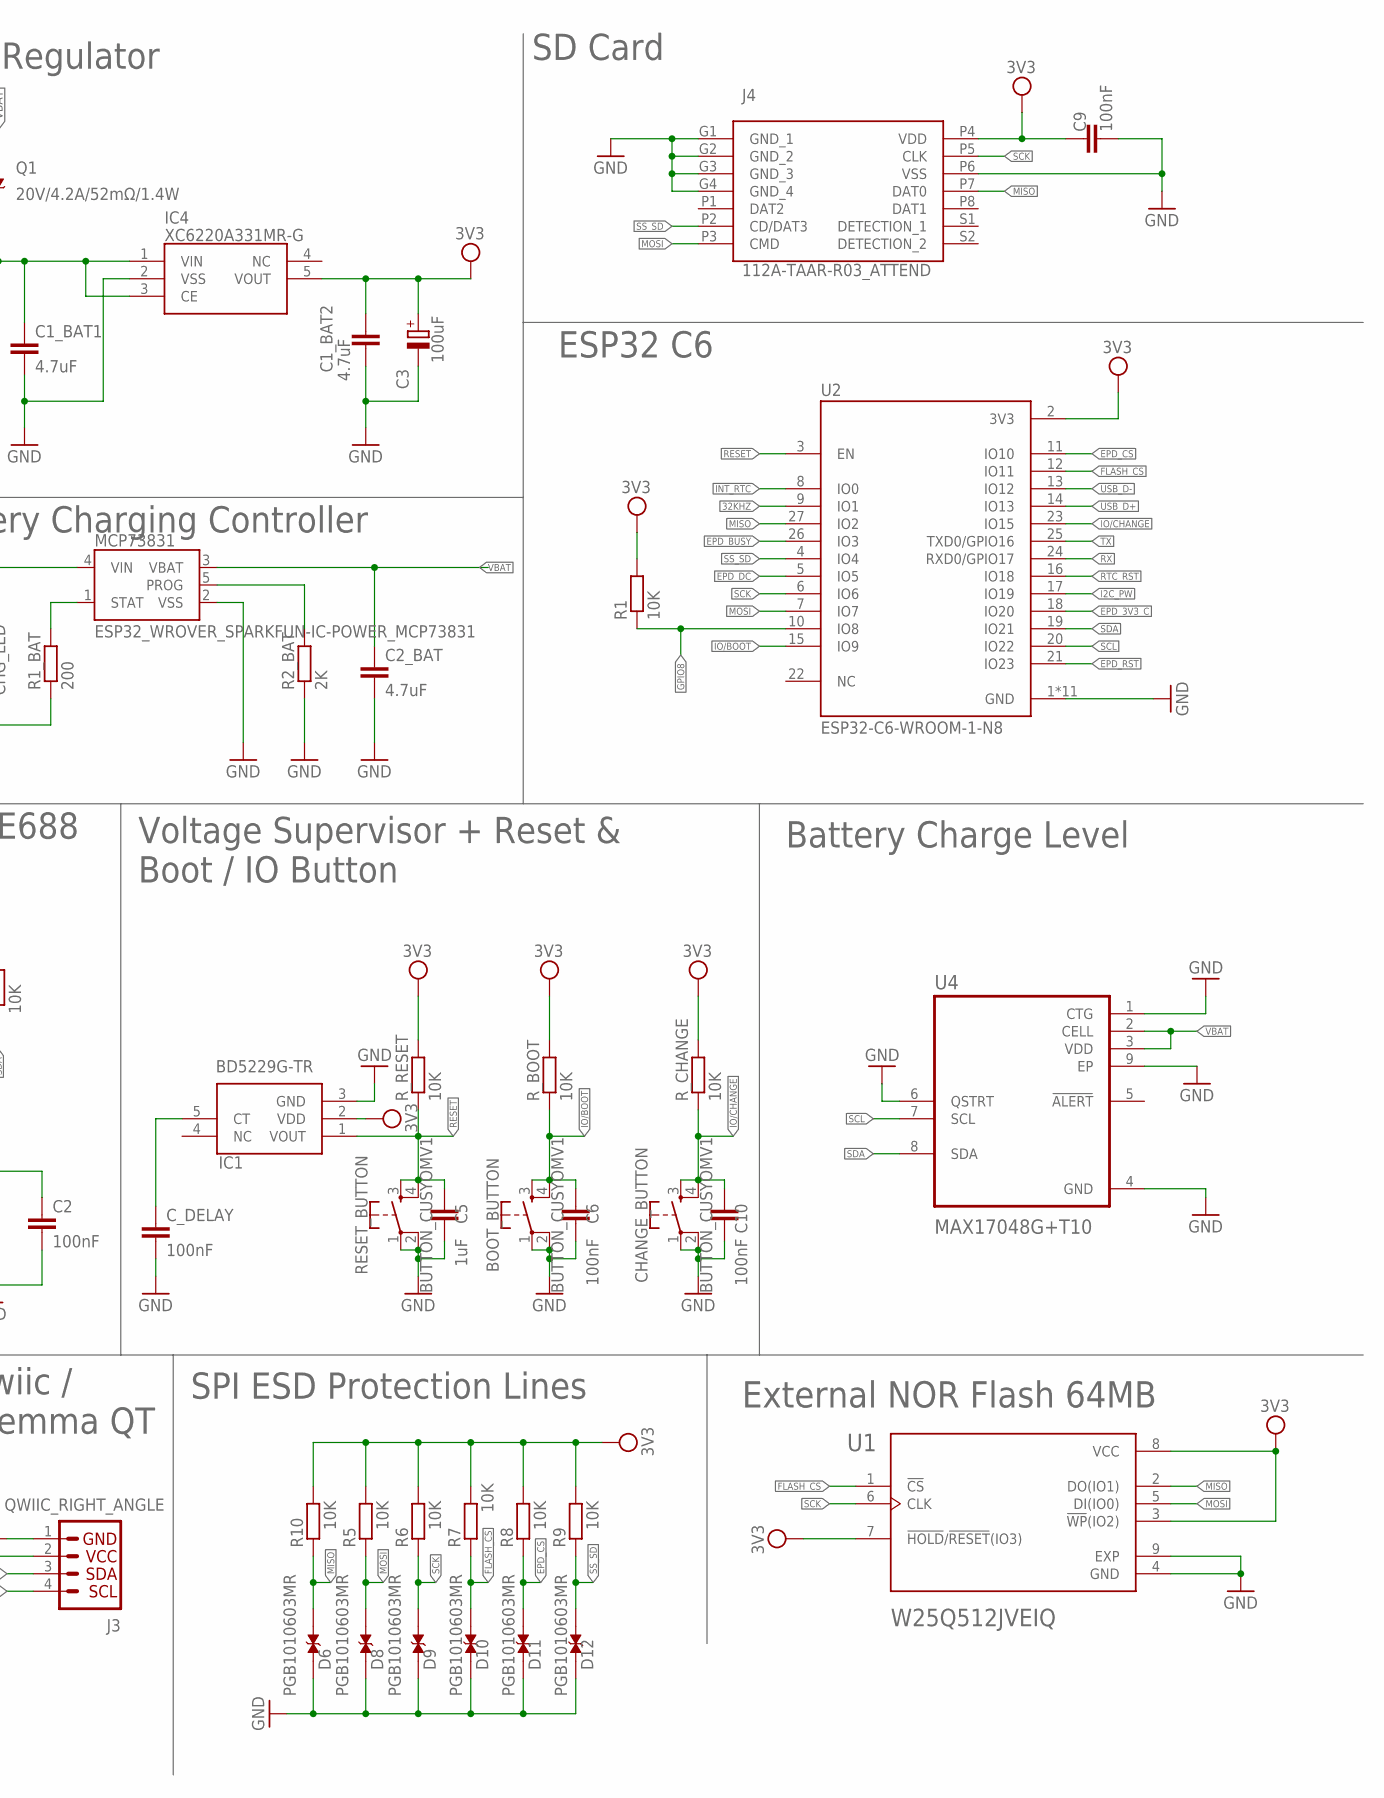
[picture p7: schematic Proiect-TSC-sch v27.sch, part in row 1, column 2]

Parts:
BOOT_BUTTON: BUTTON_CUSYOMV1; MYBUTTON
C1, C2, C4_USB, C6, C8, C9, C10: 100nF; EAGLE-LTSPICE_C0402
C1_BAT, C1_BAT2, C2_BAT, C5_USB: 4.7uF; EAGLE-LTSPICE_C0402
C1_BAT1: 4.7uF; ESP32_WROVER_EAGLE-LTSPICE_C0402
C3: 100uF; RCL_CT3528
C4: 4.7uF/25V; EAGLE-LTSPICE_C0402
C5: 1uF; EAGLE-LTSPICE_C0402
C7: 10uF; EAGLE-LTSPICE_C0402
C10_SUPERCAP: CPH3225A; CAPCP3225X100N
CHANGE_BUTTON: BUTTON_CUSYOMV1; MYBUTTON
CHG_LED: ADAFRUIT_LEDCHIP-LED0603; ADAFRUIT_CHIP-LED0603
C_DELAY: 100nF; EAGLE-LTSPICE_C0402
D1: USBLC6-2SC6Y; SOT95P280X145-6N
D2, D7: ESP32_WROVER_AVX---SD0805S020S1R0_AVX_SD0805S020S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; ESP32_WROVER_AVX---SD0805S020S1R0_AVX_SD0805S020S1R0_0
D3, D4, D5: MBR0530; SOD3716X135N
D6, D8, D9, D10, D11, D12: PGB1010603MR; DIOC1608X36N
EPD_C1, EPD_C2, EPD_C5, EPD_C6, EPD_C7, EPD_C8, EPD_C9, EPD_C10, EPD_C11, EPD_C12: 1uF/50V; EAGLE-LTSPICE_C0402
IC1: BD5229G-TR; SOT95P280X125-5N
IC4: XC6220A331MR-G; SOT95P280X120-5N
J1: FH34SRJ-24S-0.5SH_99_; FH34SRJ24S05SH99
J2: SAMACSYS_PARTS_USB4110-GF-A; SAMACSYS_PARTS_USB4110GFA
J3: QWIIC_RIGHT_ANGLE; JST04_1MM_RA
J4: 112A-TAAR-R03_ATTEND; 112ATAARR03ATTEND
L1: 68uH; IND_4828-WE-TPC_WRE
MCP73831: ESP32_WROVER_SPARKFUN-IC-POWER_MCP73831; ESP32_WROVER_SPARKFUN-IC-POWER_SOT23-5
PFMF.050.1: ESP32C6_VARISTORCN1812; ESP32C6_VARISTOR_CT/CN1812
Q1, Q2: 20V/4.2A/52mΩ/1.4W; ESP32_WROVER_SPARKFUN-DISCRETESEMI_SOT23-3
Q3: SI1308EDL-T1-GE3; SOT65P210X110-3N
R1, R1-PINH, R1_PINH1, R2-PINH, R2_PINH1, R4, R5, R6, R7, R8, R9, R10: 10K; ESP32_WROVER_EAGLE-LTSPICE_R0402
R1_BAT: 200; ESP32_WROVER_EAGLE-LTSPICE_R0402
R1_PWRUSB: 100K; ESP32_WROVER_EAGLE-LTSPICE_R0402
R2: 2.2; ESP32_WROVER_EAGLE-LTSPICE_R0402
R2-USB: 5k1; ESP32_WROVER_EAGLE-LTSPICE_R0402
R2-USB1: 5K1; ESP32_WROVER_EAGLE-LTSPICE_R0402
R2_BAT: 2K; ESP32_WROVER_EAGLE-LTSPICE_R0402
R3: 0.47; ESP32_WROVER_EAGLE-LTSPICE_R0402
RESET_BUTTON: BUTTON_CUSYOMV1; MYBUTTON
R_BOOT: 10K; ESP32_WROVER_EAGLE-LTSPICE_R0402
R_CAPACITOR: 15; ESP32_WROVER_EAGLE-LTSPICE_R0402
R_CHANGE: 10K; ESP32_WROVER_EAGLE-LTSPICE_R0402
R_CL1: 10K; ESP32_WROVER_EAGLE-LTSPICE_R0402
R_RESET: 10K; ESP32_WROVER_EAGLE-LTSPICE_R0402
SENSOR2: BME688; ESP32_WROVER_BME680_PSON80P300X300X100-8N
SJ1: SJ
TP1, TP2, TP3, TP4, TP5, TP6, TP7, TP8, TP9, TP10, TP11, TP12, TP13, TP14, TP15, TP16, TP17: TPTP20R; TP20R
U1: W25Q512JVEIQ; SON127P600X800X80-9N
U2: ESP32-C6-WROOM-1-N8; XCVR_ESP32-C6-WROOM-1-N8
U3: DS3231SN#; SOIC127P1032X265-16N
U4: MAX17048G+T10; SON50P200X200X80-9N

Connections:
3V3: C1_BAT2.1, C3.+, C9.2, D7.2 (ANODE), IC1.2 (VDD), IC4.5 (VOUT), J3.2, J4.P4 (VDD), Q2.3 (D), R1.2, R1_PINH1.2, R2_PINH1.2, R5.2, R6.2, R7.2, R8.2, R9.2, R10.2, R_BOOT.2, R_CHANGE.2, R_CL1.2, R_RESET.2, TP6.TP, U1.3 (!WP!(IO2)), U1.7 (!HOLD!/!RESET!(IO3)), U1.8 (VCC), U2.2 (3V3), U3.2 (VCC)
32KHZ: R2_PINH1.1, U2.9 (IO1), U3.1 (32KHZ)
DN: D1.4 (I/O2_2), J2.A7, J2.B7
DP: D1.6 (I/O1_2), J2.A6, J2.B6
EPD_3V3: C7.1, EPD_C5.2, J1.15, J1.16, L1.2, Q2.2 (S), TP7.TP
EPD_3V3_C: Q2.1 (G), R_CL1.1, TP15.TP, U2.18 (IO20)
EPD_BUSY: J1.9, TP11.TP, U2.26 (IO3)
EPD_CS: D11.2, J1.12, R8.1, TP12.TP, U2.11 (IO10)
EPD_DC: J1.11, TP13.TP, U2.5 (IO5)
EPD_RST: J1.10, TP14.TP, U2.21 (IO23)
FLASH_CS: D10.2, R7.1, U1.1 (!CS), U2.12 (IO11)
GDR: J1.2, Q3.1 (G), R4.2
GND: BOOT_BUTTON.1, BOOT_BUTTON.2, C1.2, C1_BAT.2, C1_BAT1.2, C1_BAT2.2, C2.2, C2_BAT.2, C3.-, C4_USB.2, C5.2, C5_USB.2, C6.2, C7.2, C8.2, C9.1, C10.2, C10_SUPERCAP.1, CHANGE_BUTTON.1, CHANGE_BUTTON.2, C_DELAY.2, D1.2 (GND), D3.1 (K), D6.1, D8.1, D9.1, D10.1, D11.1, D12.1, EPD_C1.1, EPD_C2.1, EPD_C5.1, EPD_C6.1, EPD_C7.1, EPD_C8.1, EPD_C9.1, EPD_C10.1, EPD_C11.1, EPD_C12.1, IC1.3 (GND), IC4.2 (VSS), J1.8, J1.17, J1.MP1, J1.MP2, J2.A1, J2.A12, J2.B1, J2.B12, J2.MP1, J2.MP2, J2.MP3, J2.MP4, J3.1, J4.G1 (GND_1), J4.G2 (GND_2), J4.G3 (GND_3), J4.G4 (GND_4), J4.P6 (VSS), MCP73831.2 (VSS), R1_PWRUSB.1, R2.1, R2-USB.2, R2-USB1.1, R2_BAT.1, R4.1, RESET_BUTTON.1, RESET_BUTTON.2, SENSOR2.1 (GND), SENSOR2.5 (SDO), SENSOR2.7 (GND), SJ1.1, TP4.TP, TP5.TP, U1.4 (GND), U1.9 (EXP), U2.1 (GND), U2.28 (GND), U2.29_1 (GND), U2.29_2 (GND), U2.29_3 (GND), U2.29_4 (GND), U2.29_5 (GND), U2.29_6 (GND), U2.29_7 (GND), U2.29_8 (GND), U2.29_9 (GND), U3.13 (GND), U4.1 (CTG), U4.4 (GND), U4.6 (QSTRT), U4.9 (EP)
GPIO8: R1.1, U2.10 (IO8)
I2C_PW: C1.1, C2.1, R1-PINH.2, R2-PINH.2, SENSOR2.2 (CSB), SENSOR2.6 (VDDIO), SENSOR2.8 (VDD), U2.17 (IO19)
INT_RTC: R1_PINH1.1, TP17.TP, U2.8 (IO0), U3.3 (SQW/!INT)
IO/BOOT: BOOT_BUTTON.3, BOOT_BUTTON.4, C6.1, R_BOOT.1, U2.15 (IO9)
IO/CHANGE: C10.1, CHANGE_BUTTON.3, CHANGE_BUTTON.4, R_CHANGE.1, U2.23 (IO15)
MISO: D6.2, J4.P7 (DAT0), R10.1, TP8.TP, U1.2 (DO(IO1)), U2.27 (IO2)
MOSI: D8.2, J1.14, J4.P3 (CMD), R5.1, TP9.TP, U1.5 (DI(IO0)), U2.7 (IO7)
unnamed: J2.A5, R2-USB1.2
unnamed: J2.B5, R2-USB.1
unnamed: C_DELAY.1, IC1.5 (CT)
unnamed: MCP73831.1 (STAT), R1_BAT.2
unnamed: C1_BAT1.1, D2.1 (CATHODE), IC4.1 (VIN), IC4.3 (CE), Q1.2 (S)
unnamed: C4.1, D3.2 (A), D4.1 (K)
unnamed: CHG_LED.C, R1_BAT.1
unnamed: MCP73831.5 (PROG), R2_BAT.2
unnamed: EPD_C12.2, J1.24
unnamed: EPD_C10.2, J1.22
unnamed: EPD_C8.2, J1.20
unnamed: EPD_C7.2, J1.19
unnamed: EPD_C6.2, J1.18
unnamed: EPD_C2.2, J1.5
unnamed: EPD_C1.2, J1.4
unnamed: D7.1 (CATHODE), R_CAPACITOR.1
PREVGH: D5.1 (K), EPD_C9.2, J1.21
PREVGL: D4.2 (A), EPD_C11.2, J1.23
RESE: J1.3, Q3.2 (S), R3.2
RESE': R2.2, R3.1, SJ1.2
RESET: C5.1, IC1.1 (VOUT), RESET_BUTTON.3, RESET_BUTTON.4, R_RESET.1, U2.3 (EN)
RTC_RST: U2.16 (IO18), U3.4 (!RST)
RX: TP2.TP, U2.24 (RXD0/GPIO17)
SCK: D9.2, J1.13, J4.P5 (CLK), R6.1, TP10.TP, U1.6 (CLK), U2.6 (IO6)
SCL: J3.4, R2-PINH.1, SENSOR2.4 (SCK), U2.20 (IO22), U3.16 (SCL), U4.7 (SCL)
SDA: J3.3, R1-PINH.1, SENSOR2.3 (SDI), U2.19 (IO21), U3.15 (SDA), U4.8 (SDA)
SRC: C4.2, D5.2 (A), L1.1, Q3.3 (D)
SS_SD: D12.2, J4.P2 (CD/DAT3), R9.1, U2.4 (IO4)
TX: TP1.TP, U2.25 (TXD0/GPIO16)
USB_D+: D1.1 (I/O1_1), U2.14 (IO13)
USB_D-: D1.3 (I/O2_1), U2.13 (IO12)
VBAT: C2_BAT.1, MCP73831.3 (VBAT), Q1.3 (D), TP3.TP, U4.2 (CELL), U4.3 (VDD)
VBUS: C1_BAT.1, C4_USB.1, C5_USB.1, CHG_LED.A, D1.5 (VBUS), D2.2 (ANODE), MCP73831.4 (VIN), PFMF.050.1.2, Q1.1 (G), R1_PWRUSB.2, TP16.TP
VRTC: C8.1, C10_SUPERCAP.2, R_CAPACITOR.2, U3.14 (VBAT)
VUSB: J2.A4, J2.A9, J2.B4, J2.B9, PFMF.050.1.1

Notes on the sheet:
LDO Voltage Regulator
USB C connector & ESD protection
SD Card
ESP32 C6
Display Type Selector
E-Paper Drive Circuit
Li-Po Battery Charging Controller
E-Paper Display Header
EPD Power
Environmental Sensor BME688
Voltage Supervisor + Reset & Boot / IO Button
Battery Charge Level
RTC Module DS3231SN
Test Pads
Qwiic / Stemma QT
SPI ESD Protection Lines
External NOR Flash 64MB

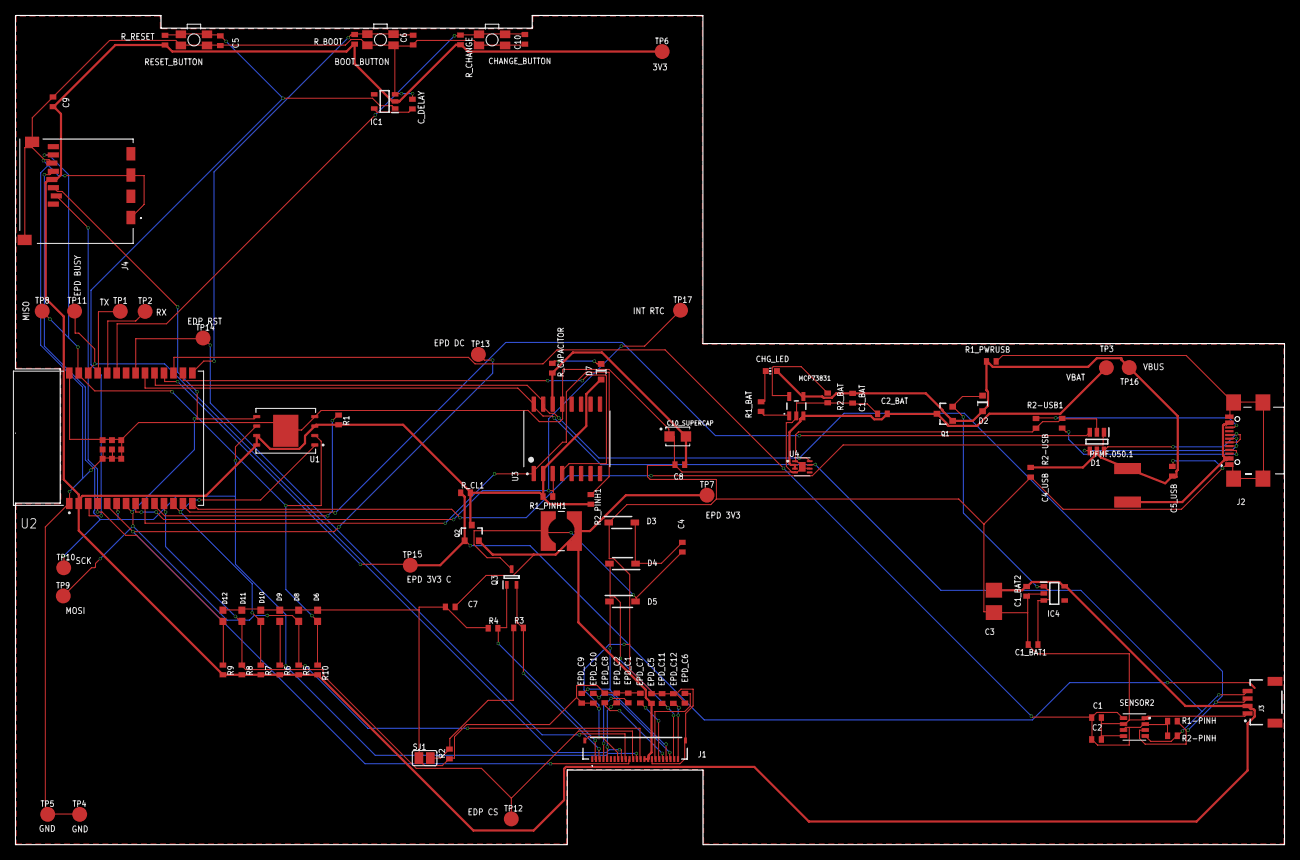
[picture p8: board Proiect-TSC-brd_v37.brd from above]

Board: 2 copper layers, 170.2 x 111.2 mm, 103 parts (0 on the bottom side), 55 nets.

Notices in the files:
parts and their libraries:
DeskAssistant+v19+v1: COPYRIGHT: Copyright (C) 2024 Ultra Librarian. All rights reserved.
